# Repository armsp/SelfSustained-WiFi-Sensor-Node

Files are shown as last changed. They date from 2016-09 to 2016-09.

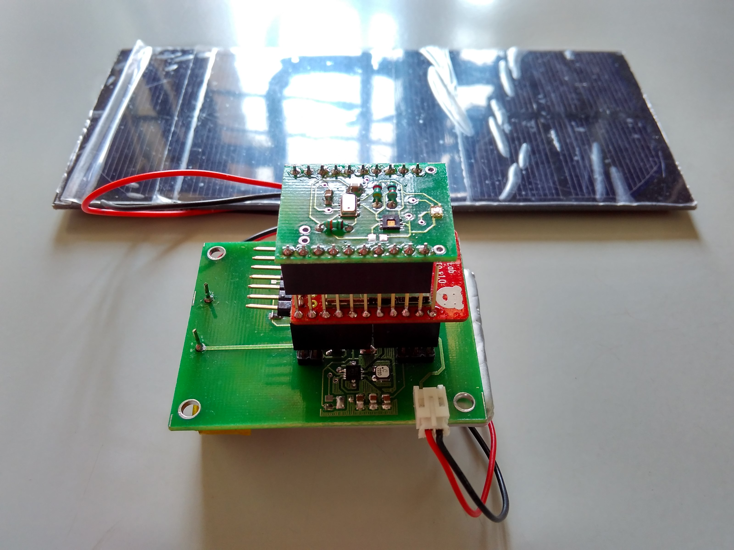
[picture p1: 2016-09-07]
Pictures/sswsn.jpg

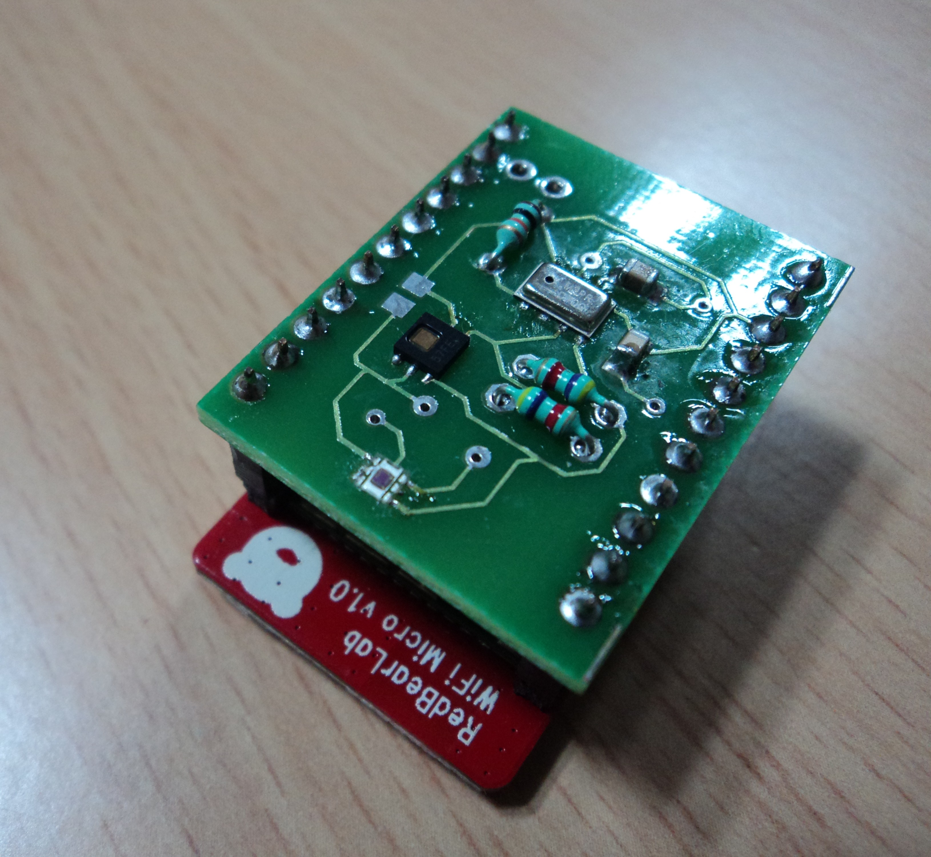
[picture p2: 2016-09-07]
Pictures/sensor_hub.jpg

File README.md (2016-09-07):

# Self Sustained WiFi Sensor Node using CC3200 SoC and Energy Harvesting with BQ25505/BQ25570
Complete Details regarding the project can be found at my Blog https://shantamraj.wordpress.com
You can also visit my Hackster.io profile for the same at https://www.hackster.io/shantam

I am working on taking this project and the overall idea behind it to next level. The updates regarding that will be posted soon.

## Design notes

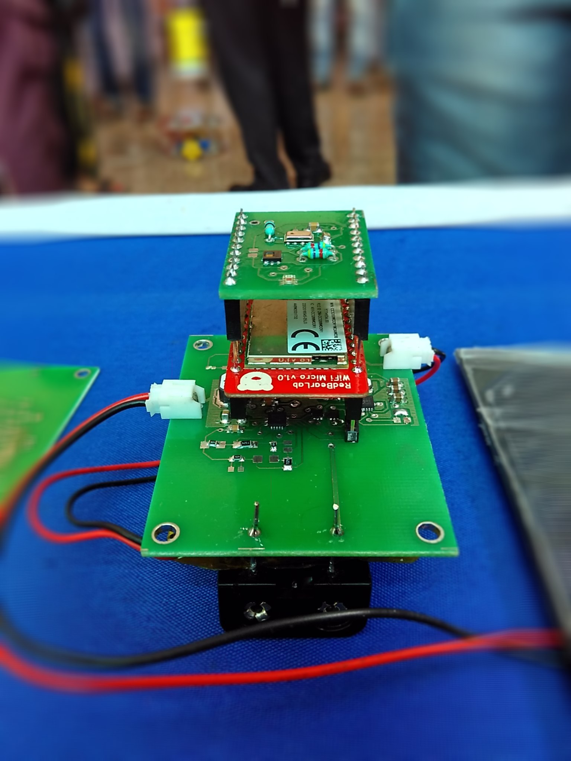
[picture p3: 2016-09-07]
Pictures/sswsn3.jpg

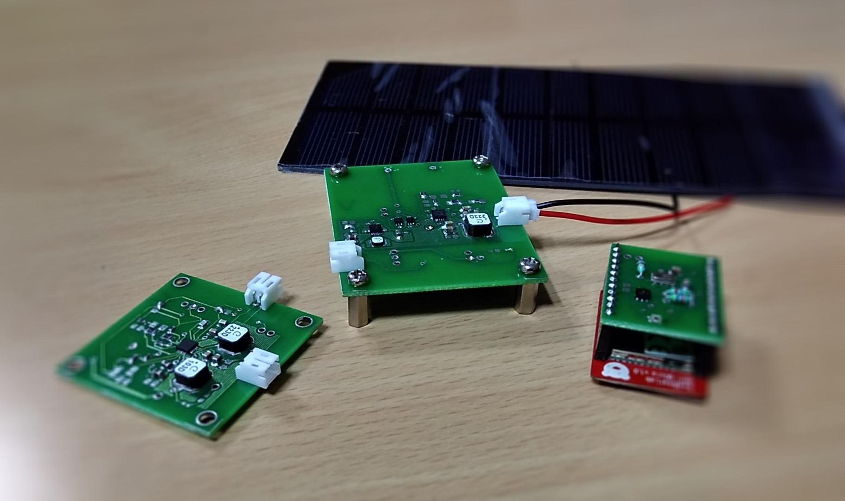
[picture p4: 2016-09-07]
Pictures/together.jpg

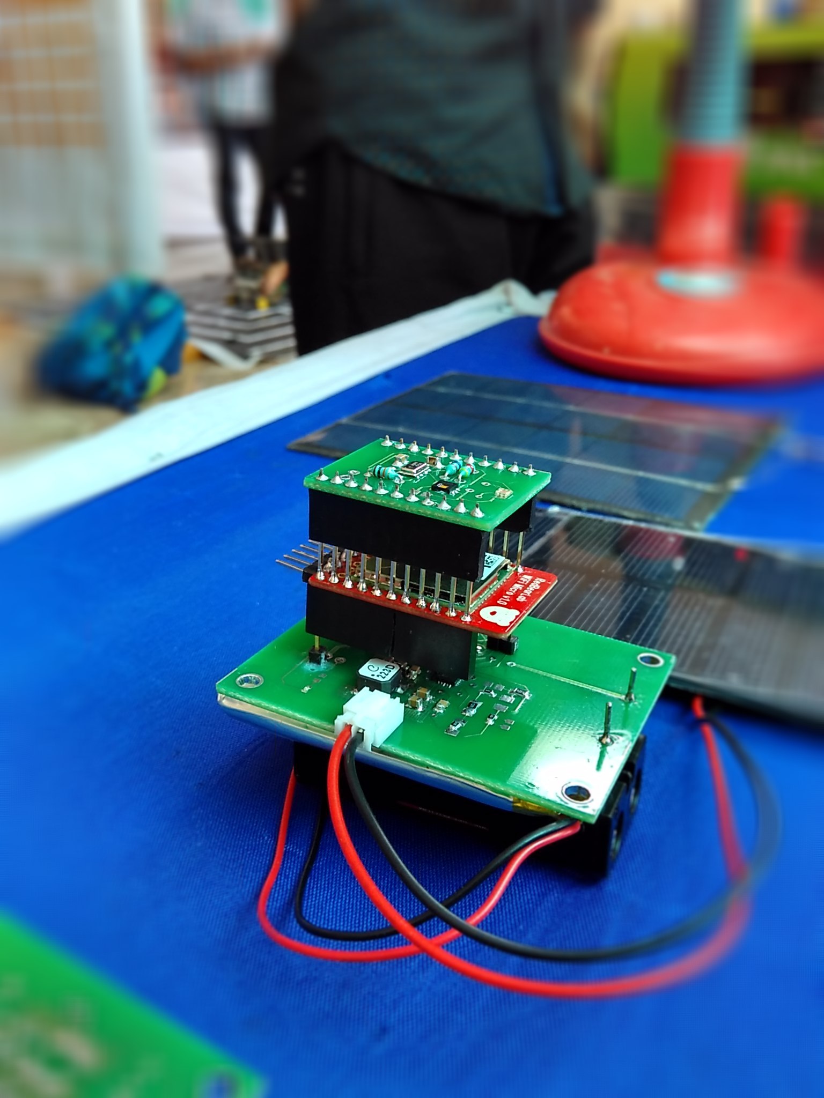
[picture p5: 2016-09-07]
Pictures/sswsn2.jpg

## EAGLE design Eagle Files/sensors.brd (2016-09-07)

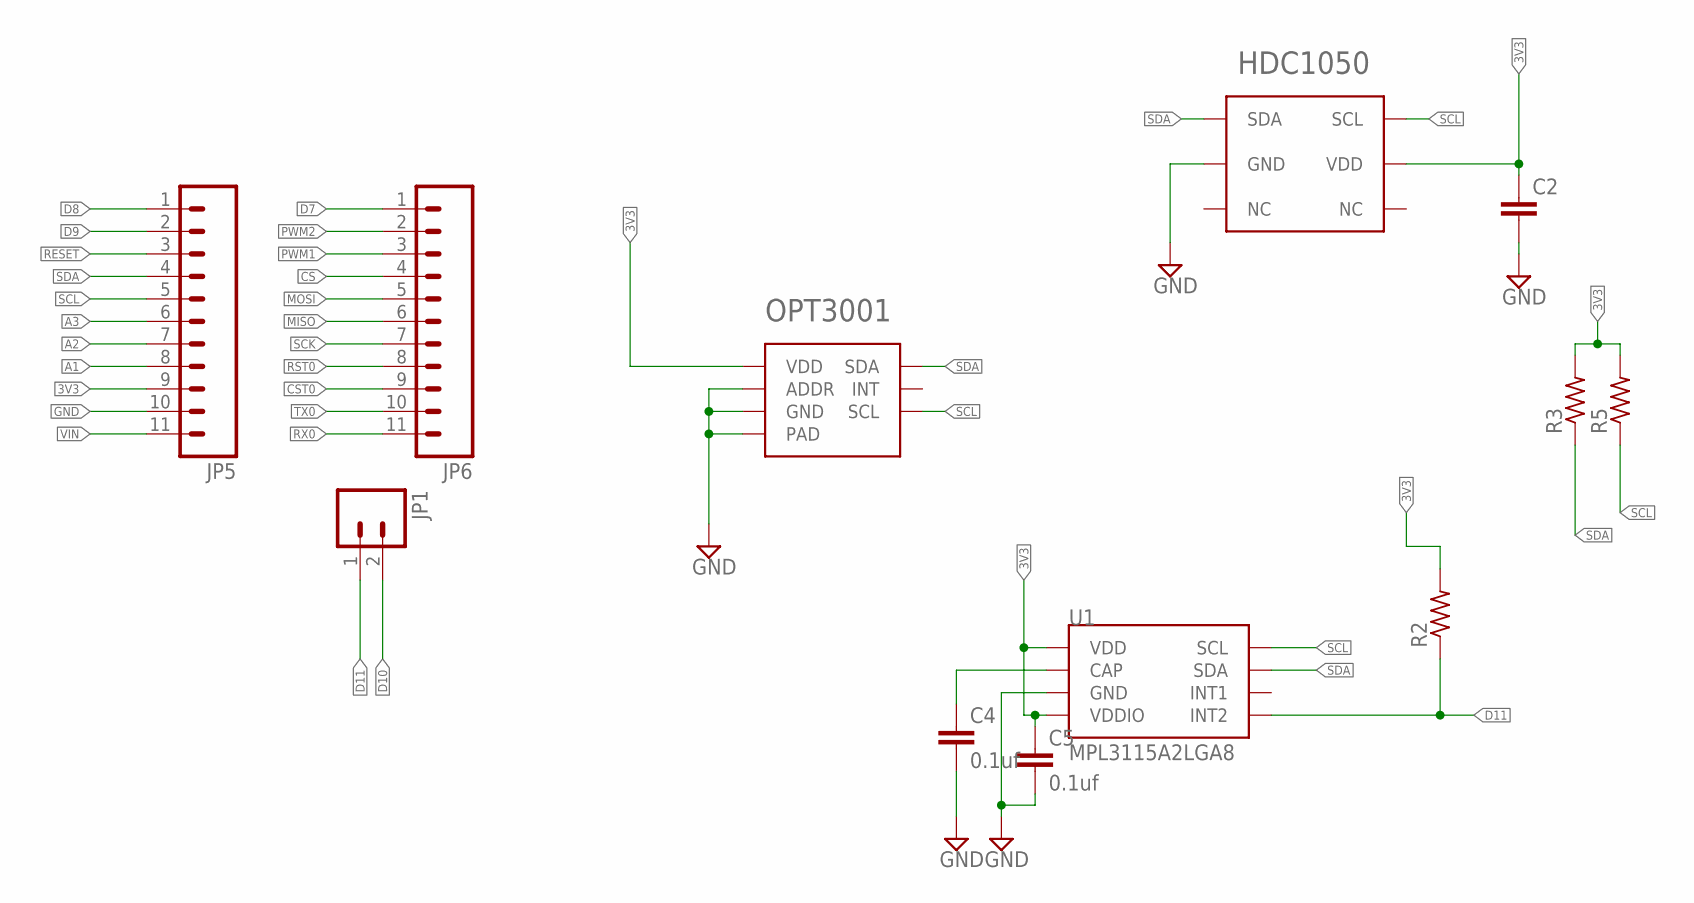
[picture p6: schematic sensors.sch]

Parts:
C2: C-EUC0805; C0805
C4, C5: 0.1uf; C0805
HDC1050: HDC1050; PWSON-6
JP1: M02PTH; 1X02
JP5, JP6: M11PTH; 1X11
OPT3001: OPT3001
R2, R3, R5: R-US_0204/5; 0204/5
U1: MPL3115A2LGA8; LGA8

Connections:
3V3: C2.1, C5.1, HDC1050.P$5 (VDD), JP5.9, OPT3001.P$1 (VDD), R2.2, R3.2, R5.2, U1.1 (VDD), U1.4 (VDDIO)
A1: JP5.8
A2: JP5.7
A3: JP5.6
CS: JP6.4
CST0: JP6.9
D7: JP6.1
D8: JP5.1
D9: JP5.2
D10: JP1.2
D11: JP1.1, R2.1, U1.5 (INT2)
GND: C2.2, C4.2, C5.2, HDC1050.P$2 (GND), JP5.10, OPT3001.P$2 (ADDR), OPT3001.P$3 (GND), OPT3001.P$7 (PAD), U1.3 (GND)
MISO: JP6.6
MOSI: JP6.5
unnamed: C4.1, U1.2 (CAP)
PWM1: JP6.3
PWM2: JP6.2
RESET: JP5.3
RST0: JP6.8
RX0: JP6.11
SCK: JP6.7
SCL: HDC1050.P$6 (SCL), JP5.5, OPT3001.P$4 (SCL), R5.1, U1.8 (SCL)
SDA: HDC1050.P$1 (SDA), JP5.4, OPT3001.P$6 (SDA), R3.1, U1.7 (SDA)
TX0: JP6.10
VIN: JP5.11

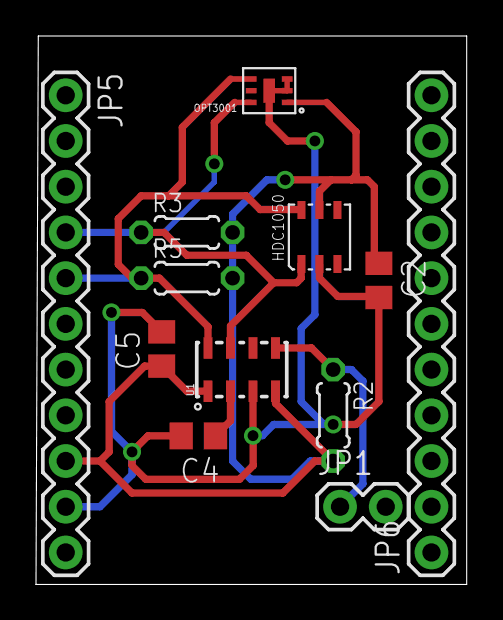
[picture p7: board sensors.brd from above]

Board: 2 copper layers, 23.9 x 30.5 mm, 12 parts (0 on the bottom side), 6 nets.

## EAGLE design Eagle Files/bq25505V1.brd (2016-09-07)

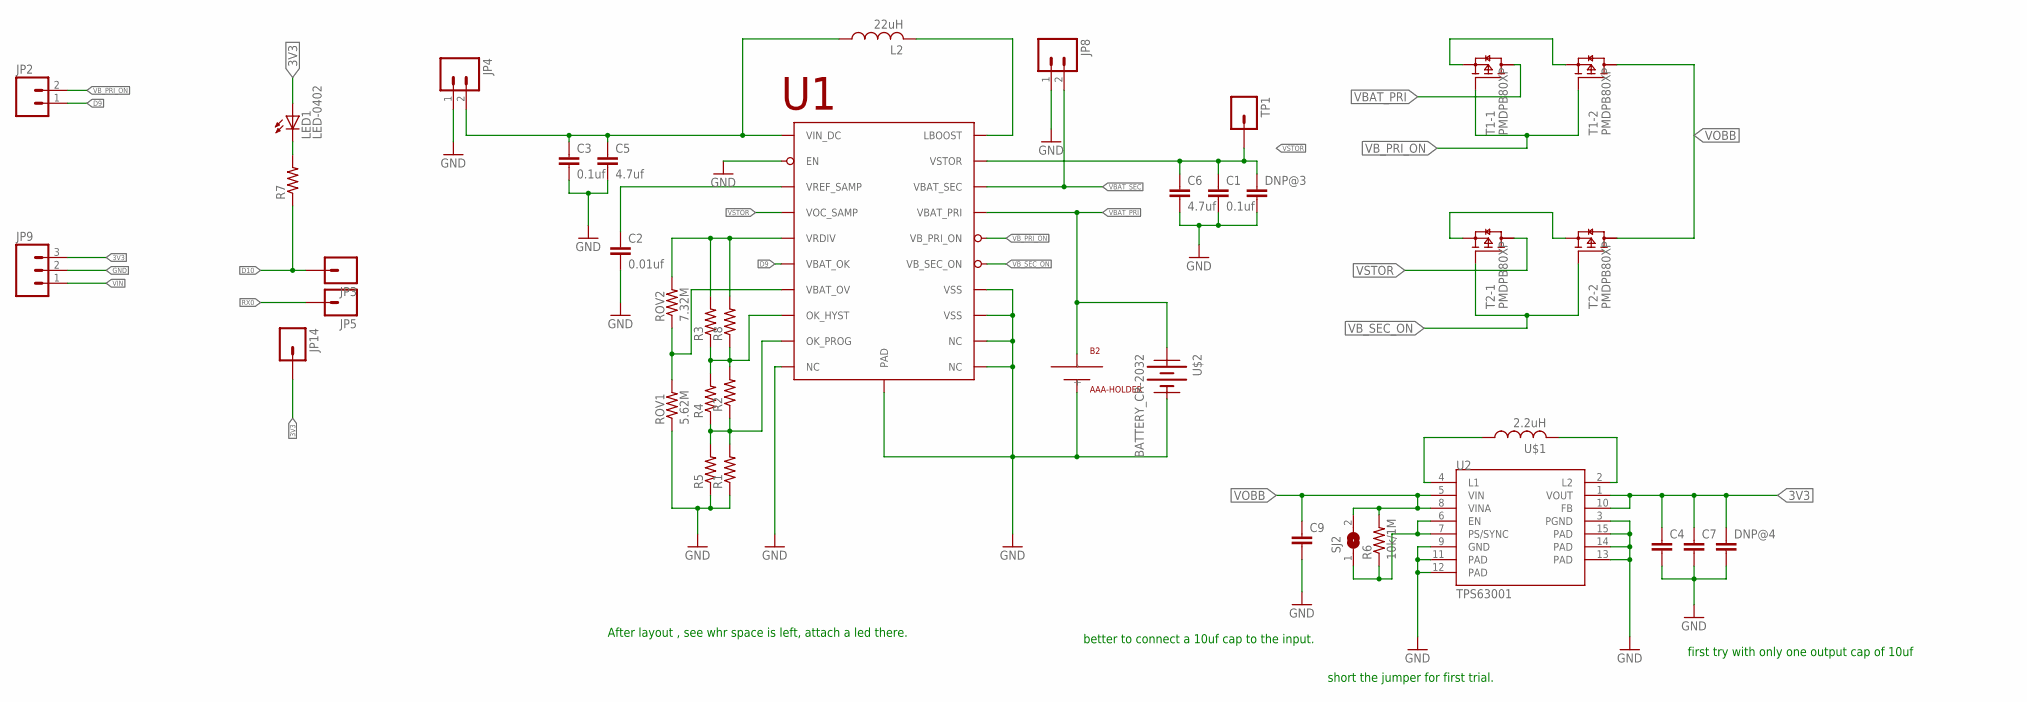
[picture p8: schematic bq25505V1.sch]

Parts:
B2: AAA-HOLDER; AAA-BATTERY
C1, C3: 0.1uf; C0805
C2: 0.01uf; C0805
C4, C7, C9: C-EUC0805; C0805
C5, C6: 4.7uf; C0805
DNP@3, DNP@4: C-EUC0805; C0805
JP2: M02PTH; 1X02
JP3, JP5, JP14: M01PTH; 1X01
JP4, JP8: M02-JST-2-PTH-NO_SILK; JST-2-PTH-NS
JP9: M03PTH; 1X03
L2: 22uH; LPS6235
LED1: LED-0402; 0402
R1, R3, R5, R7: R-US_R0603; R0603
R2, R8: R-US_R0805; R0805
R4: R-US_R1206; R1206
R6: 10k/1M; R0805
ROV1: 5.62M; R1206
ROV2: 7.32M; R1206
SJ2: SJ
T1, T2: PMDPB80XP; SOT1118
TP1: M01PTH; 1X01
U1: BQ25505; VQFN-20
U2: TPS63001; QFN-10_PAD
U$1: 2.2uH; LPS3010
U$2: BATTERY_CR-2032; BATTCON_20MM

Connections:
3V3: C4.1, C7.1, DNP@4.1, JP9.3, JP14.1, LED1.P$1 (A), U2.1 (VOUT), U2.10 (FB)
D9: JP2.1, U1.P$13 (VBAT_OK)
D10: JP3.1, R7.1
GND: B2.P$2 (-), C1.2, C2.2, C3.2, C4.2, C5.2, C6.2, C7.2, C9.2, DNP@3.2, DNP@4.2, JP4.1, JP8.1, JP9.2, R1.1, R5.1, ROV1.1, U1.P$1 (VSS), U1.P$5 (EN), U1.P$6 (NC), U1.P$15 (VSS), U1.P$16 (NC), U1.P$17 (NC), U1.P$21 (PAD), U2.3 (PGND), U2.9 (GND), U2.11 (PAD), U2.12 (PAD), U2.13 (PAD), U2.14 (PAD), U2.15 (PAD), U$2.2 (-2)
L1: U2.4 (L1), U$1.P$1 (1)
L2: U2.2 (L2), U$1.P$2 (2)
LBOOST: L2.P$2 (2), U1.P$20 (LBOOST)
unnamed: C2.1, U1.P$4 (VREF_SAMP)
unnamed: T1.1 (S), T1.4 (S)
unnamed: T2.1 (S), T2.4 (S)
unnamed: LED1.P$2 (C), R7.2
OK_HYST: R2.2, R3.1, R4.2, R8.1, U1.P$11 (OK_HYST)
OK_PROG: R1.2, R2.1, R4.1, R5.2, U1.P$12 (OK_PROG)
PS/SYNC: R6.1, SJ2.1, U2.6 (EN), U2.7 (PS/SYNC)
RX0: JP5.1
VBAT_OV: ROV1.2, ROV2.1, U1.P$7 (VBAT_OV)
VBAT_PRI: B2.P$1 (+), T1.6 (D), T1.7 (D), U1.P$14 (VBAT_PRI), U$2.1 (+2), U$2.3 (+2)
VBAT_SEC: JP8.2, U1.P$18 (VBAT_SEC)
VB_PRI_ON: JP2.2, T1.2 (G), T1.5 (G), U1.P$10 (VB_PRI_ON)
VB_SEC_ON: T2.2 (G), T2.5 (G), U1.P$9 (VB_SEC_ON)
VIN: JP9.1
VIN_DC: C3.1, C5.1, JP4.2, L2.P$1 (1), U1.P$2 (VIN_DC)
VOBB: C9.1, R6.2, SJ2.2, T1.3 (D), T1.8 (D), T2.3 (D), T2.8 (D), U2.5 (VIN), U2.8 (VINA)
VRDIV: R3.2, R8.2, ROV2.2, U1.P$8 (VRDIV)
VSTOR: C1.1, C6.1, DNP@3.1, T2.6 (D), T2.7 (D), TP1.1, U1.P$3 (VOC_SAMP), U1.P$19 (VSTOR)

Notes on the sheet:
After layout , see whr space is left, attach a led there.
first try with only one output cap of 10uf
short the jumper for first trial.
better to connect a 10uf cap to the input.

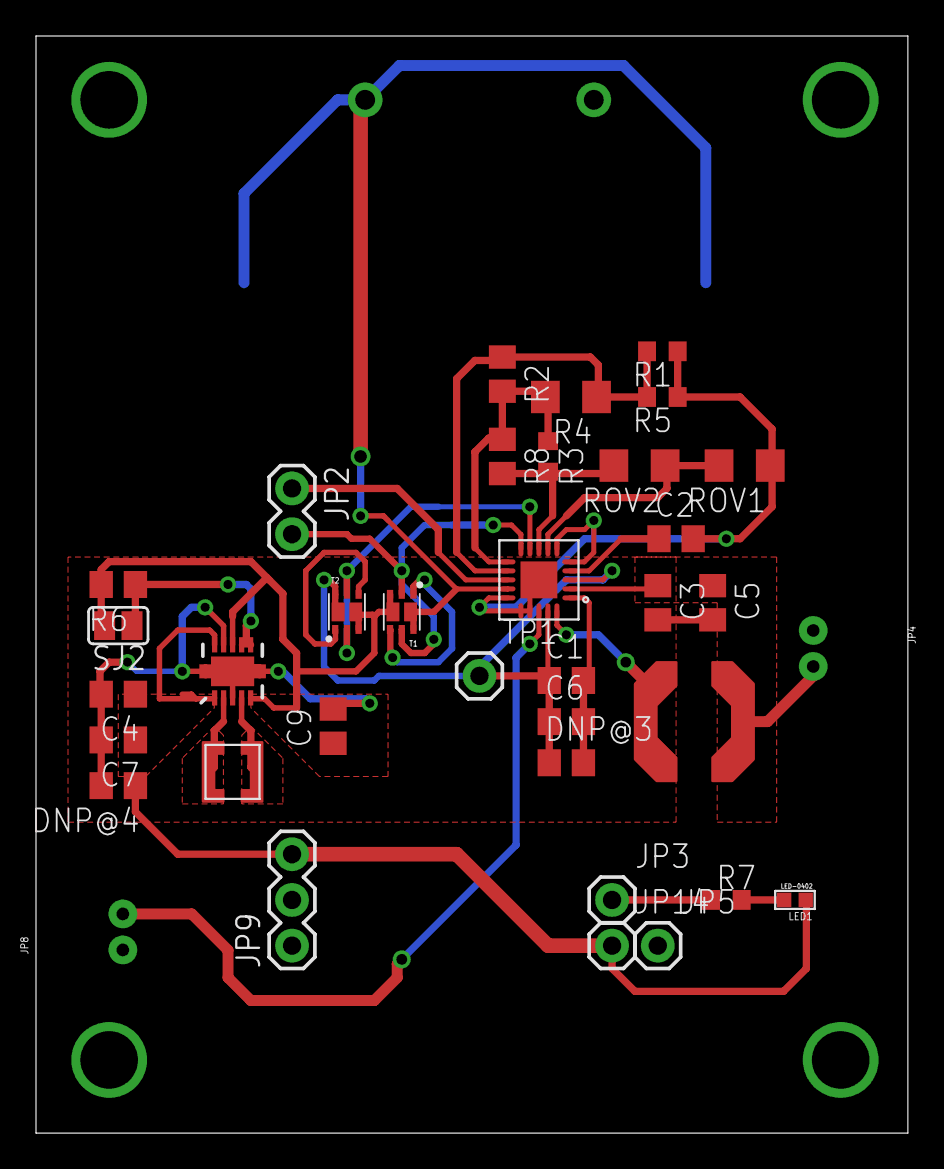
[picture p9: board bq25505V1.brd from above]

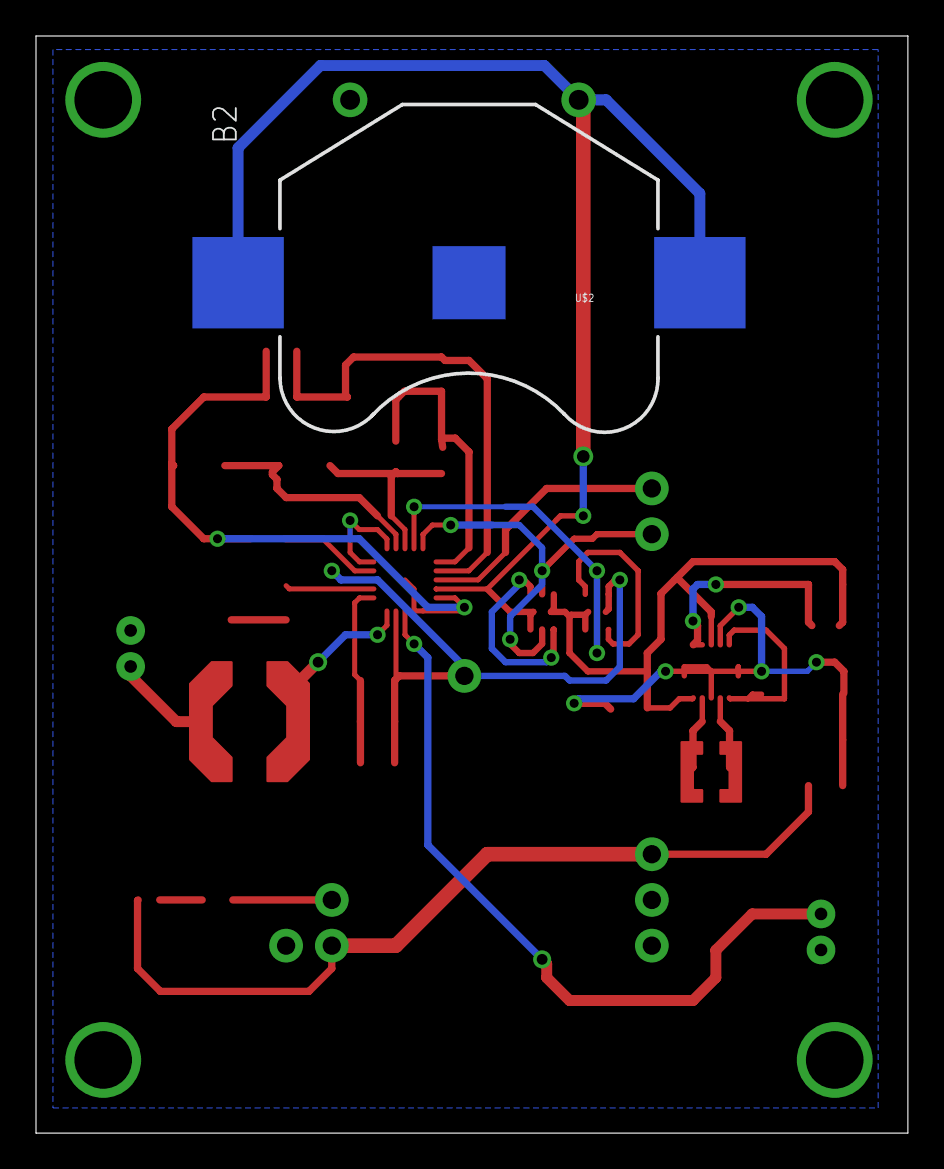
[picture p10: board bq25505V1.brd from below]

Board: 2 copper layers, 48.4 x 61.0 mm, 38 parts (2 on the bottom side), 23 nets.

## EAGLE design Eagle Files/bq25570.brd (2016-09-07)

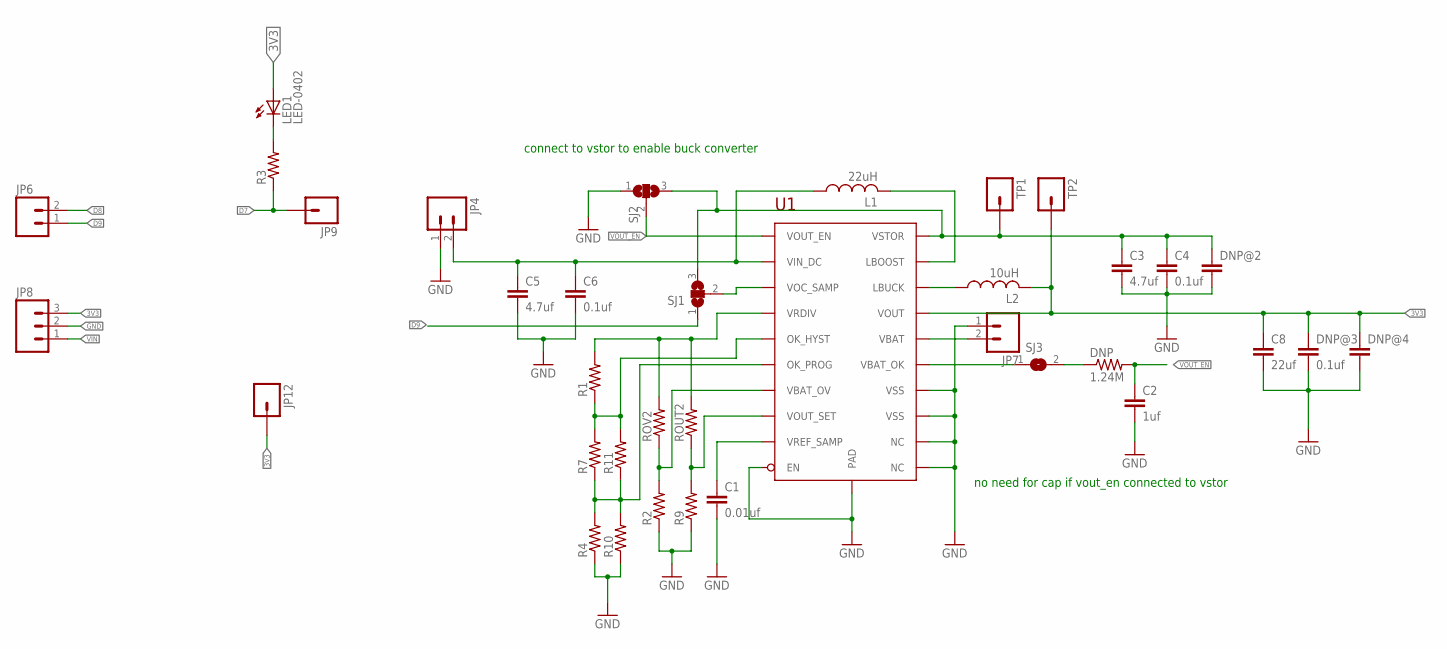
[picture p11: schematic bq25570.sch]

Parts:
C1: 0.01uf; C0805
C2: 1uf; C0805
C3, C5: 4.7uf; C0805
C4, C6: 0.1uf; C0805
C8: 22uf; C0805
DNP: 1.24M; M0805
DNP@2, DNP@4: C-EUC0805; C0805
DNP@3: 0.1uf; C0805
JP4, JP7: M02-JST-2-PTH-NO_SILK; JST-2-PTH-NS
JP6: M02PTH; 1X02
JP8: M03PTH; 1X03
JP9, JP12: M01PTH; 1X01
L1: 22uH; LPS6235
L2: 10uH; LPS6235
LED1: LED-0402; 0402
R1, R2, R3, R4: R-US_R0603; R0603
R7, R9, R10: R-US_R0805; R0805
R11: R-US_R1206; R1206
ROUT2: R-US_R0603; R0603
ROV2: R-US_R0805; R0805
SJ1, SJ2: SJ2W; SJ_2
SJ3: SJ
TP1, TP2: M01PTH; 1X01
U1: BQ25570; QFN-20

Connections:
3V3: C8.1, DNP@3.1, DNP@4.1, JP8.3, JP12.1, L2.P$2 (2), LED1.P$1 (A), TP2.1, U1.P$14 (VOUT)
D7: JP9.1, R3.1
D8: JP6.2
D9: JP6.1, SJ1.1
GND: C1.2, C2.2, C3.2, C4.2, C5.2, C6.2, C8.2, DNP@2.2, DNP@3.2, DNP@4.2, JP4.1, JP7.1, JP8.2, R2.1, R4.1, R9.1, R10.1, SJ2.1, U1.P$1 (VSS), U1.P$5 (EN), U1.P$9 (NC), U1.P$15 (VSS), U1.P$17 (NC), U1.P$21 (PAD)
unnamed: L1.P$2 (2), U1.P$20 (LBOOST)
unnamed: L2.P$1 (1), U1.P$16 (LBUCK)
unnamed: SJ1.2, U1.P$3 (VOC_SAMP)
unnamed: JP7.2, U1.P$18 (VBAT)
unnamed: C1.1, U1.P$4 (VREF_SAMP)
unnamed: SJ3.1, U1.P$13 (VBAT_OK)
unnamed: R1.2, ROUT2.2, ROV2.2, U1.P$8 (VRDIV)
unnamed: DNP.1, SJ3.2
unnamed: R9.2, ROUT2.1, U1.P$12 (VOUT_SET)
unnamed: R2.2, ROV2.1, U1.P$7 (VBAT_OV)
unnamed: R1.1, R7.2, R11.2, U1.P$10 (OK_HYST)
unnamed: LED1.P$2 (C), R3.2
unnamed: R4.2, R7.1, R10.2, R11.1, U1.P$11 (OK_PROG)
VIN: JP8.1
VIN_DC: C5.1, C6.1, JP4.2, L1.P$1 (1), U1.P$2 (VIN_DC)
VOUT_EN: C2.1, DNP.2, SJ2.2, U1.P$6 (VOUT_EN)
VSTOR: C3.1, C4.1, DNP@2.1, SJ1.3, SJ2.3, TP1.1, U1.P$19 (VSTOR)

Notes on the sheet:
connect to vstor to enable buck converter
no need for cap if vout_en connected to vstor

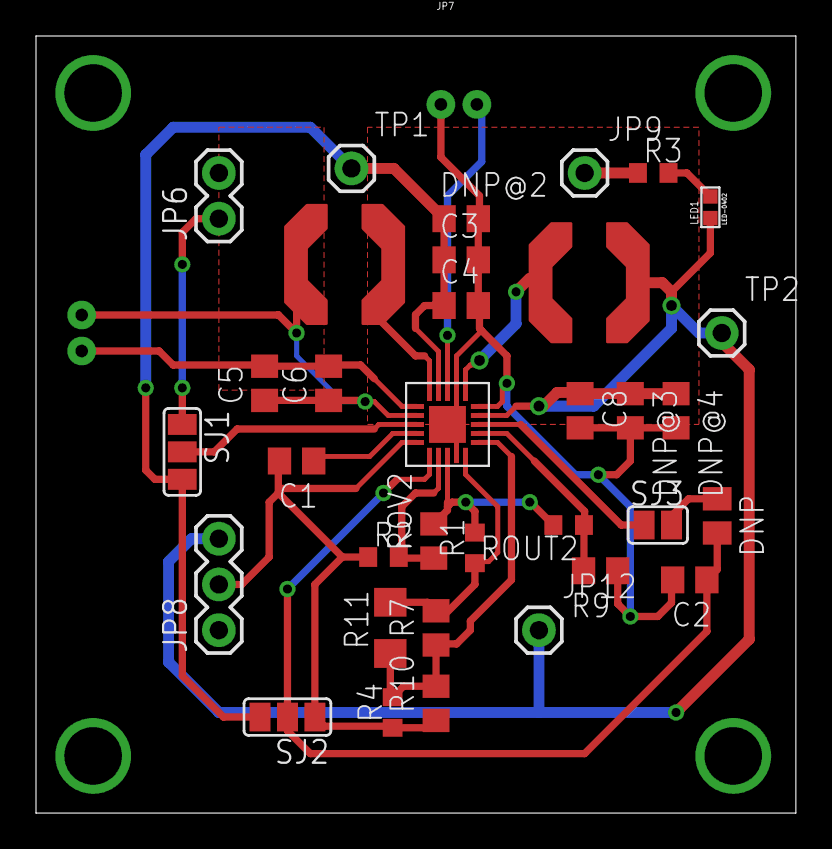
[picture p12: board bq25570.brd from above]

Board: 2 copper layers, 42.2 x 43.2 mm, 36 parts (0 on the bottom side), 20 nets.

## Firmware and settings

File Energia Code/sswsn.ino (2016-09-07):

// Best code so far, works with both router and mobile phone hotspot!!. The graphing also works!!.
#include <adafruitmpl.h>
#include <HDC1050-v2.h>
#include <utils.h>
#include <OPT3001.h>
//#include <SPI.h>
#include <WiFi.h>
//#include <WiFiClient.h>
//#include <WiFiServer.h>
#include <Wire.h>
opt3001 instance;
uint32_t resultt =0;
HDC1000 mySensor;
Adafruit_MPL3115A2 baro = Adafruit_MPL3115A2();
float pascals;
float altm ;
float tempC ;
float hdctemp ;
float hdchumi ;

// your network name also called SSID
char ssid[] = "******";
// your network password
char password[] = "*******";
// your network key Index number (needed only for WEP)
int keyIndex = 0;

WiFiServer server(80);
int i = 0;
void setup() {
  Serial.begin(115200);      // initialize serial communication
  pinMode(RED_LED, OUTPUT);      // set the LED pin mode
  instance.begin();
  mySensor.begin();
  baro.begin();
  // attempt to connect to Wifi network:
  Serial.print("Attempting to connect to Network named: ");
  // print the network name (SSID);
  Serial.println(ssid);
  // Connect to WPA/WPA2 network. Change this line if using open or WEP network:
  WiFi.begin(ssid, password);
  while ( WiFi.status() != WL_CONNECTED) {
    // print dots while we wait to connect
    Serial.print(".");
    delay(300);
  }

  Serial.println("\nYou're connected to the network");
  Serial.println("Waiting for an ip address");

  while (WiFi.localIP() == INADDR_NONE) {
    // print dots while we wait for an ip addresss
    Serial.print(".");
    delay(300);
  }

  // you're connected now, so print out the status
  printWifiStatus();

  Serial.println("Starting webserver on port 80");
  server.begin();                           // start the web server on port 80
  Serial.println("Webserver started!");

}
void loop() {
  getSensorData();
//  resultt = instance.readResult();
//  //Serial.println(resultt);
//  float pascals = baro.getPressure();
//  float altm = baro.getAltitude();
//  float tempC = baro.getTemperature();
//  double hdctemp = mySensor.getTemp();
//  double hdchumi = mySensor.getHumi();

  // listen for incoming clients
  WiFiClient client = server.available();
  if (client) {
    Serial.println("new client");
    // an http request ends with a blank line
    boolean currentLineIsBlank = true;
    while (client.connected()) {
      if (client.available()) {
        char c = client.read();
        Serial.write(c);
        // if you've gotten to the end of the line (received a newline
        // character) and the line is blank, the http request has ended,
        // so you can send a reply
        if (c == '\n' && currentLineIsBlank) {
          // send a standard http response header
          client.println("HTTP/1.1 200 OK");
          client.println("Content-Type: text/html; charset=utf-8");
          //Content-Type: text/html; charset=utf-8
          client.println("Connection: close");  // the connection will be closed after completion of the response
          client.println("Refresh: 5");  // refresh the page automatically every 5 sec
          client.println("Access-Control-Allow-Origin: *"); //comment this line if u are facing issues showing things on webpage.
          client.println();
          //client.println("<!DOCTYPE HTML>");
          //client.println("<html>");
          client.println("<html>");
          client.print("LUX:");
          client.print(resultt);
          client.print(";");
          client.print("Temperature:");
          client.print(hdctemp);
          client.print(";Humidity:");
          client.print(hdchumi);
          client.print(";");
          client.print("  ");
          client.print("Hg:");
          client.print(pascals/3377);
          client.print(";Height:");
          client.print(altm); //client.print("m ");
          client.print(";Temp:");
          client.print(tempC); //client.print("*C");
          client.println("<br>");
          client.println("</html>");
          client.println();
          break;
        }
        if (c == '\n') {
          // you're starting a new line
          currentLineIsBlank = true;
        }
        else if (c != '\r') {
          // you've gotten a character on the current line
          currentLineIsBlank = false;
        }
      }
    }
    // give the web browser time to receive the data
    delay(1);

    // close the connection:
    client.stop();
    Serial.println("client disonnected");
  }
  i++;
}
void printWifiStatus() {
  // print the SSID of the network you're attached to:
  Serial.print("Network Name: ");
  Serial.println(WiFi.SSID());

  // print your WiFi shield's IP address:
  IPAddress ip = WiFi.localIP();
  Serial.print("IP Address: ");
  Serial.println(ip);

  // print the received signal strength:
  long rssi = WiFi.RSSI();
  Serial.print("signal strength (RSSI):");
  Serial.print(rssi);
  Serial.println(" dBm");
}
void getSensorData(){
  resultt = instance.readResult();
  Serial.println(resultt);
  pascals = baro.getPressure();
  Serial.println(pascals);
  altm = baro.getAltitude();
  Serial.println(altm);
  tempC = baro.getTemperature();
  Serial.println(tempC);
  hdctemp = mySensor.getTemp();
  Serial.println(hdctemp);
  hdchumi = mySensor.getHumi();
  Serial.println(hdchumi);
}

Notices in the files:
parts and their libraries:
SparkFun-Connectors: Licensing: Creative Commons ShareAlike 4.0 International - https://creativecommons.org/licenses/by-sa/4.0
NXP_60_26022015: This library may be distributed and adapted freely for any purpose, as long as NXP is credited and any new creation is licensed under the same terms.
